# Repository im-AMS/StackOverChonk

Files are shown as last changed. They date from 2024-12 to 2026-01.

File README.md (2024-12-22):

# References

- [custom ergogen-footprints](https://github.com/ceoloide/ergogen-footprints)
- [3d models to view in kicad](https://github.com/joe-scotto/scottokeebs/tree/main/Extras/ScottoKicad)
- [josukey](https://github.com/Narkoleptika/josukey)
- [avocado](https://github.com/auryn31/avocado)
- [supermini pinout specs](https://docs.nordicsemi.com/bundle/ps_nrf52840/page/pin.html)
- [Arduino Pro Micro Pinout](https://cdn.sparkfun.com/assets/9/c/3/c/4/523a1765757b7f5c6e8b4567.png)
- [ergogen configs from Corney-island](https://github.com/ceoloide/corney-island/blob/main/ergogen/config.yaml)
- [svg to points](https://shinao.github.io/PathToPoints/)

# Renders
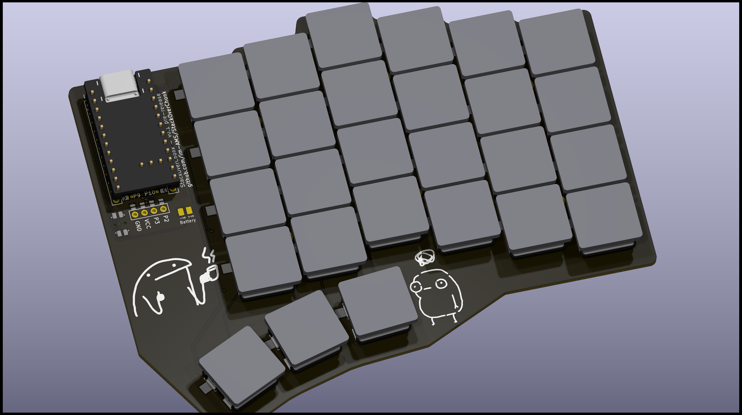
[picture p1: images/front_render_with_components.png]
Front render with components

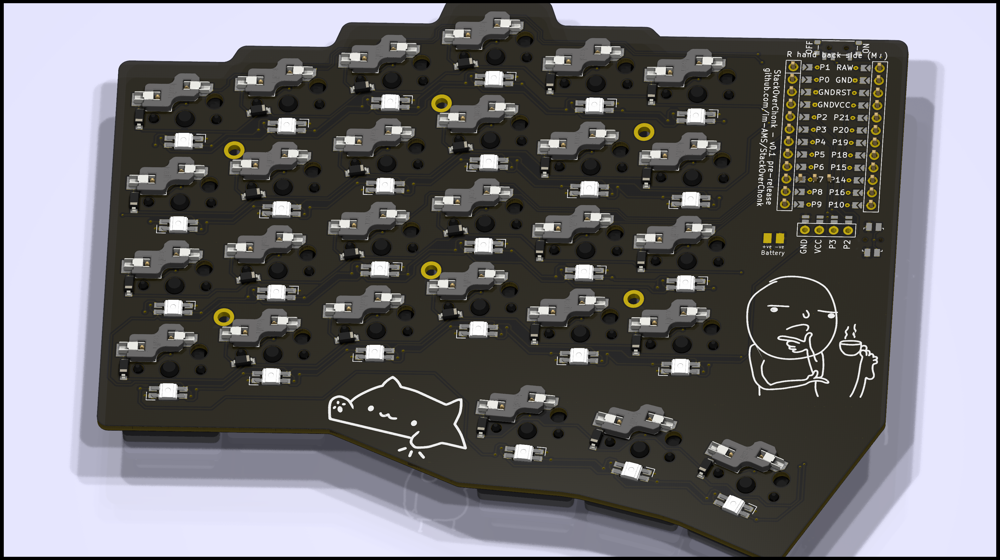
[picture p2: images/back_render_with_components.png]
Back render with components

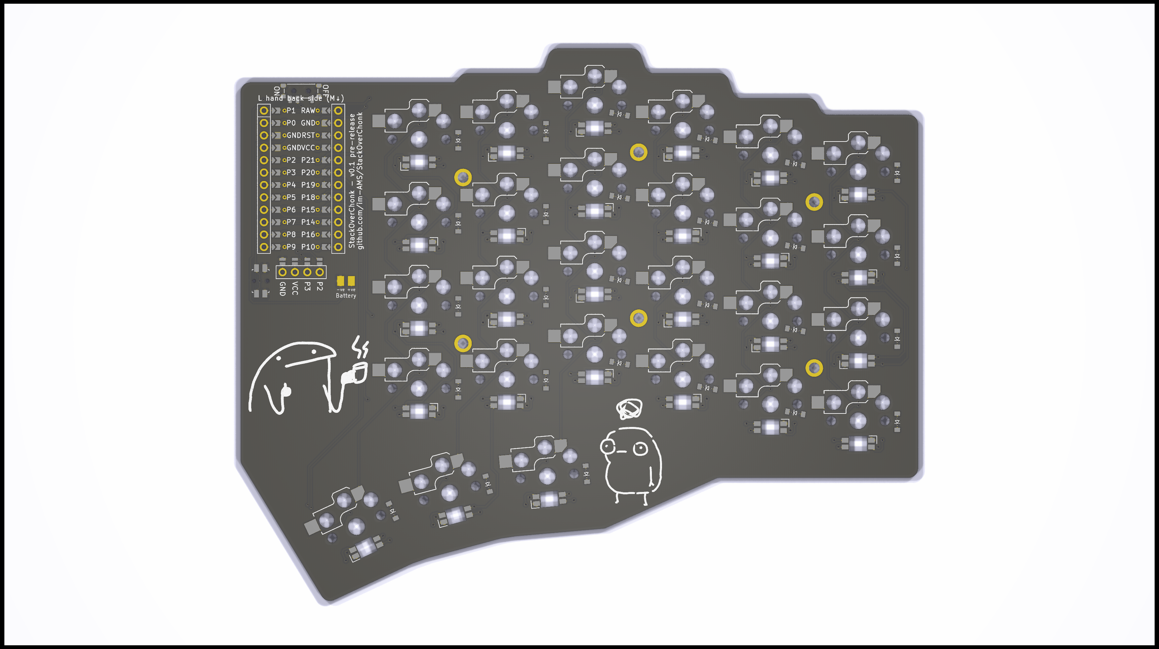
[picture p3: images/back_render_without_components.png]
Front render without components

Back render without components

# Personal Notes and Todos
For RGB Underglow, ZMK docs recomments using high speed gpio pins. refer to the attached pinout specs above.

Try to reserve pins like so (pins in arduino format)
- D2 & D3 for I2C - for Displays
- D6 for high speed comms like RGB underglow, because docs is also using it
- D14, D15, D16 - SPI - idk what i might use this for, just leave em blank

can the battery be connected to RAW for charging or do i have to connect it to top two pins

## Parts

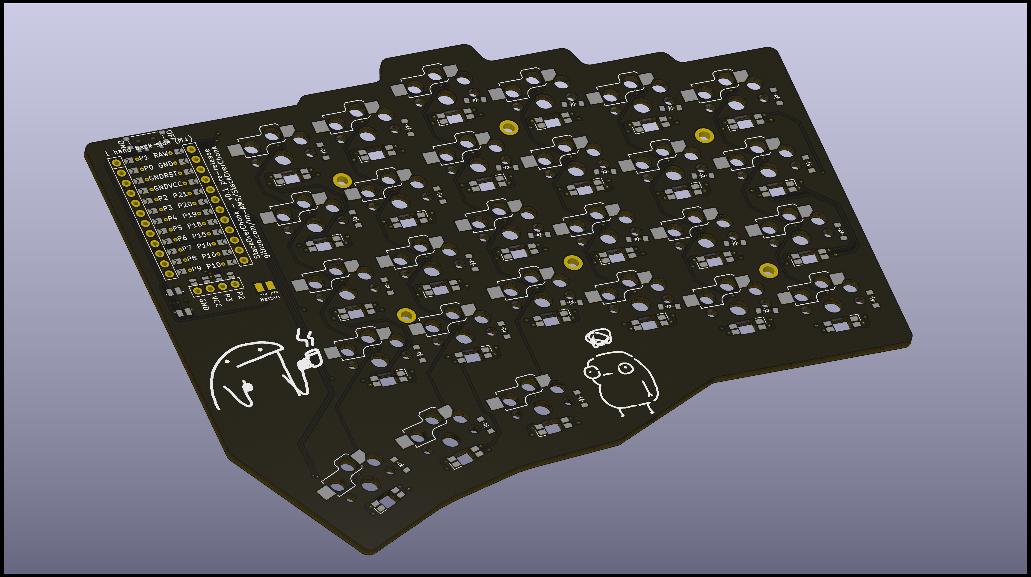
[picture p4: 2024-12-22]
images/front_render_without_components.png

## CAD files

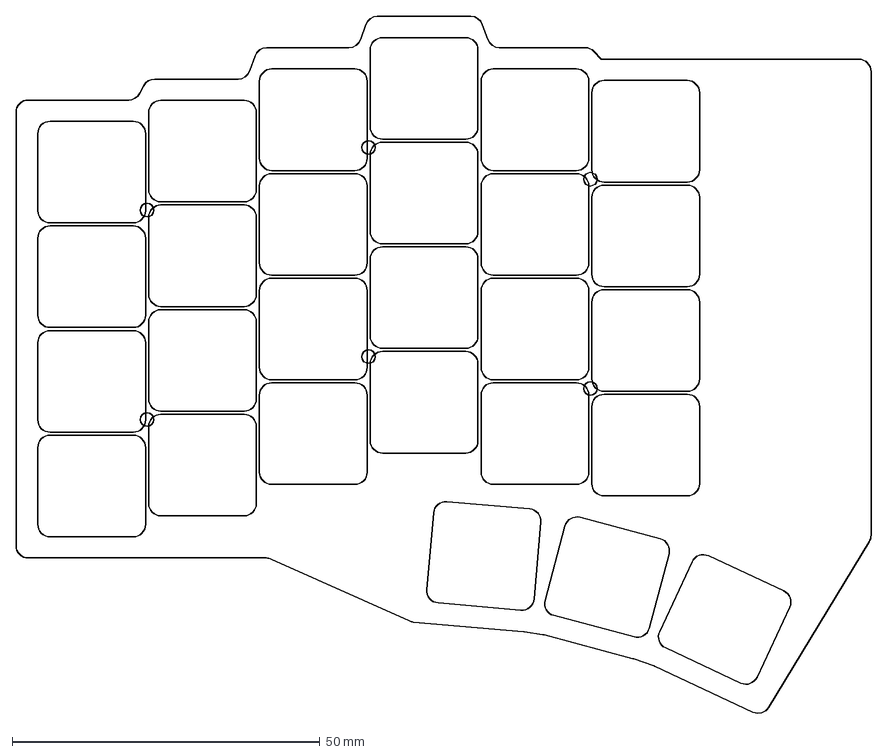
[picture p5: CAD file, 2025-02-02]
ergogen/output/outlines/preview.dxf
138.9 x 113.5 mm

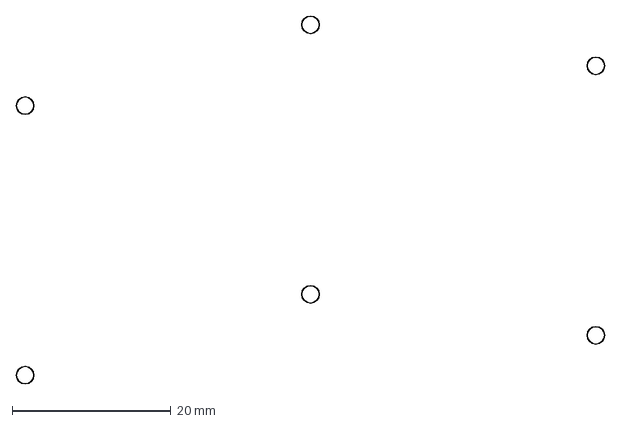
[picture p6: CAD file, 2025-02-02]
ergogen/output/outlines/mounting_holes.dxf
74.2 x 46.4 mm

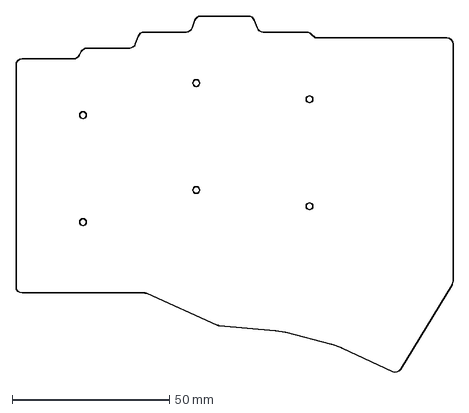
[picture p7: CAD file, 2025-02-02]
ergogen/output/outlines/board_outline.dxf
138.9 x 113.5 mm

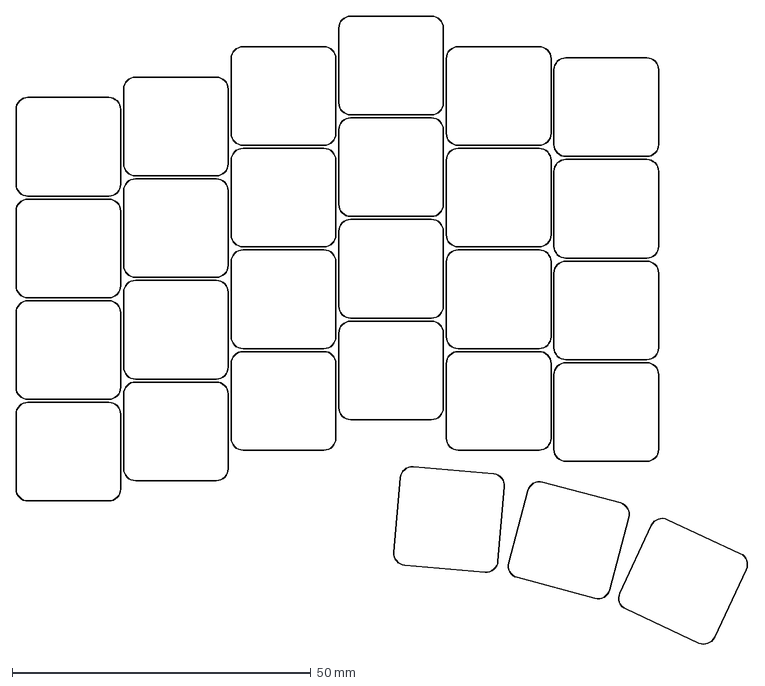
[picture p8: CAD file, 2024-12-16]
ergogen/output/outlines/keycap_outlines.dxf
122.6 x 105.3 mm

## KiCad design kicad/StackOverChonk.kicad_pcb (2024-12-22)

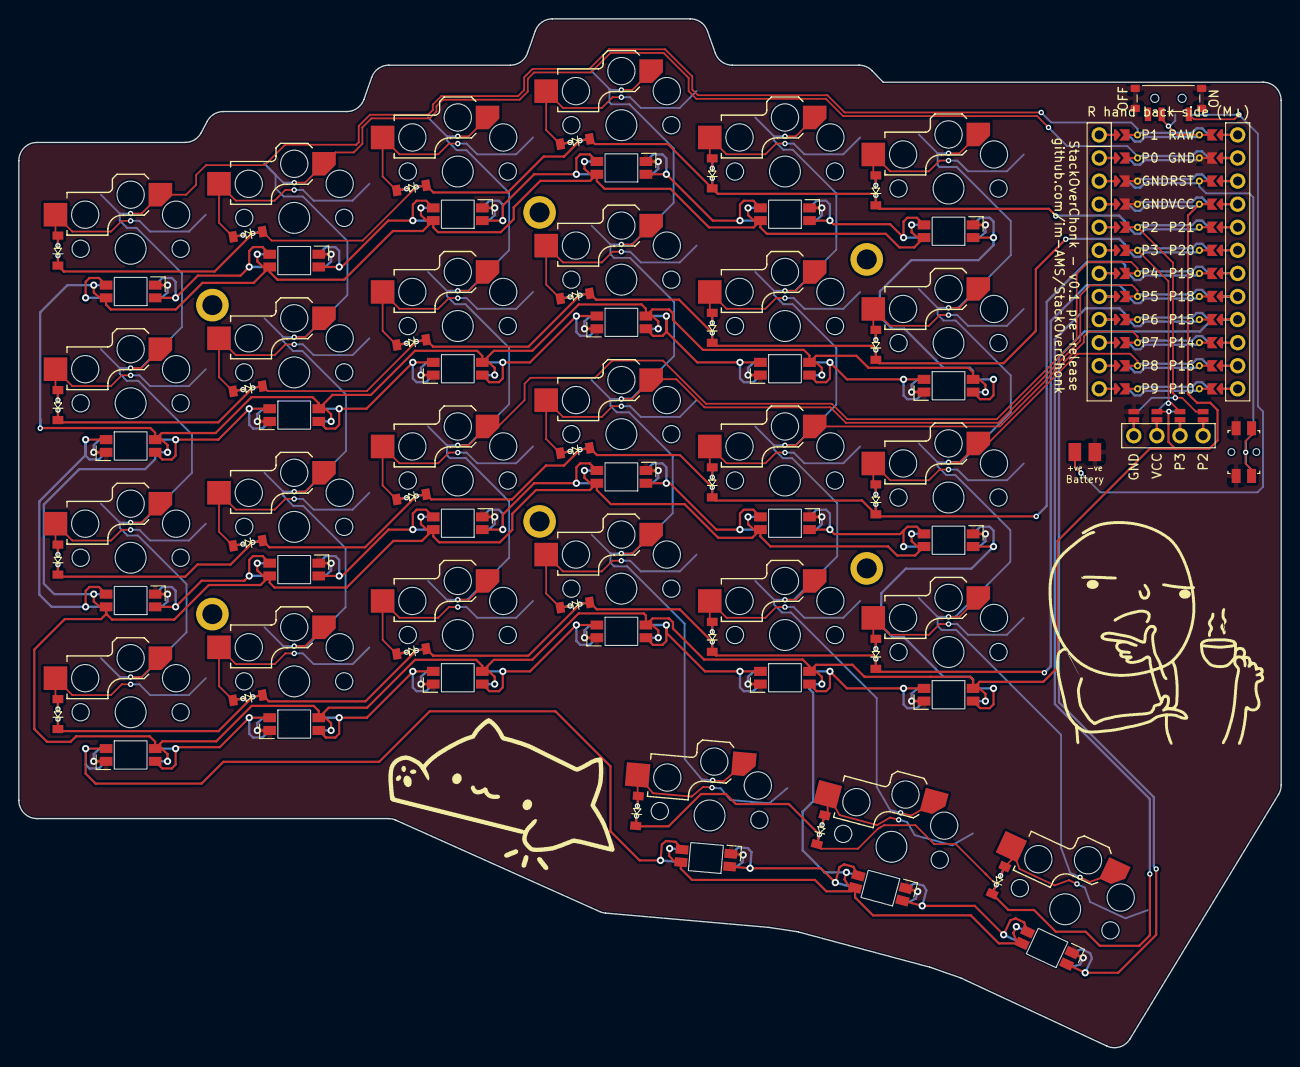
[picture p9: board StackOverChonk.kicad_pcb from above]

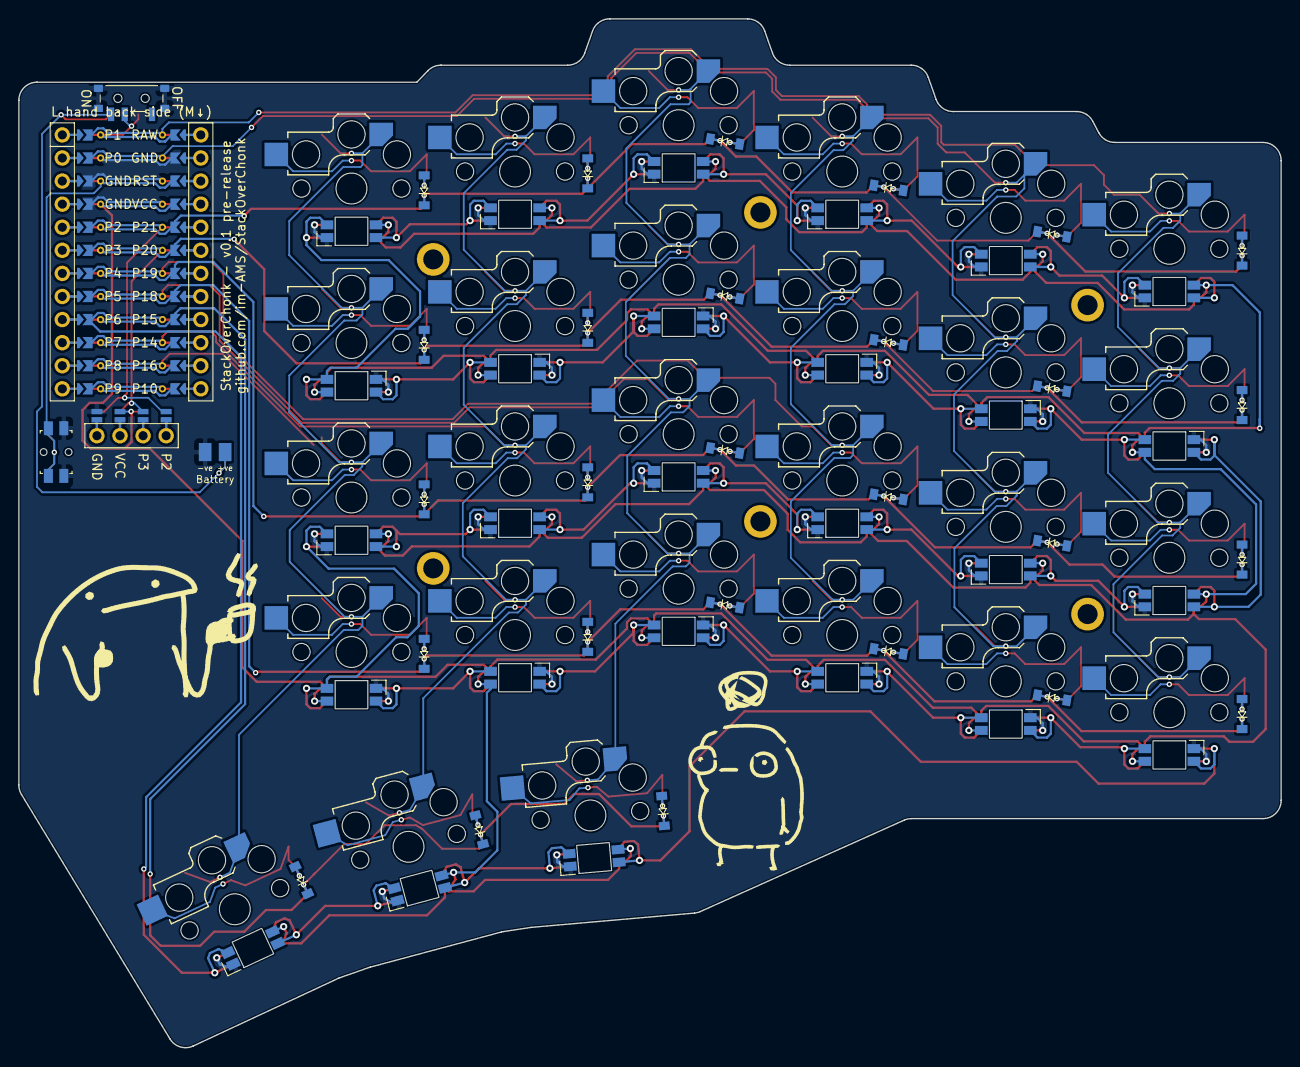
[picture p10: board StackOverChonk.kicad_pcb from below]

Board: 2 copper layers, 138.9 x 113.2 mm, 93 parts (35 on the bottom side), 76 nets.

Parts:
BT1, BT2: Battery_pads
D1, D2, D3, D4, D5, D6, D7, D8, D9, D10, D11, D12, D13, D14, D15, D16, D17, D18, D19, D20, D21, D22, D23, D24, D25, D26, D27: diode_tht_sod123
DISP1: display_ssd1306
H1, H2, H3, H4, H5, H6: mounting_hole_plated
LED1, LED2, LED3, LED4, LED5, LED6, LED7, LED8, LED9, LED10, LED11, LED12, LED13, LED14, LED15, LED16, LED17, LED18, LED19, LED20, LED21, LED22, LED23, LED24, LED25, LED26, LED27: led_SK6812mini-e (per-key, reversible)
MCU1: mcu_supermini_nrf52840
PWR1: power_switch_smd_side
RST1: reset_switch_smd_side
S1, S2, S3, S4, S5, S6, S7, S8, S9, S10, S11, S12, S13, S14, S15, S16, S17, S18, S19, S20, S21, S22, S23, S24, S25, S26, S27: switch_choc_v1_v2

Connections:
DISP1_1: DISP1.1, DISP1.10, DISP1.23
DISP1_2: DISP1.2, DISP1.11, DISP1.22
DISP1_3: DISP1.3, DISP1.12, DISP1.21
DISP1_4: DISP1.4, DISP1.13, DISP1.20
GND: BT1.2, BT2.2, DISP1.14, DISP1.24, LED1.3, LED2.3, LED3.3, LED4.3, LED5.3, LED6.3, LED7.3, LED8.3, LED9.3, LED10.3, LED11.3, LED12.3, LED13.3, LED14.3, LED15.3, LED16.3, LED17.3, LED18.3, LED19.3, LED20.3, LED21.3, LED22.3, LED23.3, LED24.3, LED25.3, LED26.3, LED27.3, MCU1.102, MCU1.121, MCU1.122, PWR1.STAB1, PWR1.STAB2, PWR1.STAB3, PWR1.STAB4, RST1.2, RST1.4
LED_1: LED26.4, LED27.2
LED_2: LED25.4, LED26.2
LED_3: LED1.4, LED25.2
LED_4: LED1.2, LED3.4
LED_5: LED3.2, LED5.4
LED_6: LED5.2, LED7.4
LED_7: LED7.2, LED9.4
LED_8: LED9.2, LED11.4
LED_9: LED11.2, LED23.4
LED_10: LED21.4, LED23.2
LED_11: LED19.4, LED21.2
LED_12: LED17.4, LED19.2
LED_13: LED15.4, LED17.2
LED_14: LED13.4, LED15.2
LED_15: LED2.4, LED13.2
LED_16: LED2.2, LED4.4
LED_17: LED4.2, LED6.4
LED_18: LED6.2, LED8.4
LED_19: LED8.2, LED10.4
LED_20: LED10.2, LED12.4
LED_21: LED12.2, LED24.4
LED_22: LED22.4, LED24.2
LED_23: LED20.4, LED22.2
LED_24: LED18.4, LED20.2
LED_25: LED16.4, LED18.2
LED_26: LED14.4, LED16.2
P0: MCU1.123, S5.1, S6.1, S7.1, S8.1
P1: MCU1.124, S1.1, S2.1, S3.1, S4.1
P2: DISP1.17, DISP1.27, MCU1.120
P3: DISP1.16, DISP1.26, MCU1.119
P4: MCU1.118, S9.1, S10.1, S11.1, S12.1
P5: MCU1.117, S13.1, S14.1, S15.1, S16.1, S25.1
P6: LED27.4, MCU1.116
P7: MCU1.115, S17.1, S18.1, S19.1, S20.1, S26.1
P8: MCU1.114, S21.1, S22.1, S23.1, S24.1, S27.1
P15: D25.1, D26.1, D27.1, MCU1.109
P18: D1.1, D5.1, D9.1, D13.1, D17.1, D21.1, MCU1.108
P19: D2.1, D6.1, D10.1, D14.1, D18.1, D22.1, MCU1.107
P20: D3.1, D7.1, D11.1, D15.1, D19.1, D23.1, MCU1.106
P21: D4.1, D8.1, D12.1, D16.1, D20.1, D24.1, MCU1.105
RAW: MCU1.101, PWR1.2
RST: MCU1.103, RST1.1, RST1.3
VCC: DISP1.15, DISP1.25, LED1.1, LED2.1, LED3.1, LED4.1, LED5.1, LED6.1, LED7.1, LED8.1, LED9.1, LED10.1, LED11.1, LED12.1, LED13.1, LED14.1, LED15.1, LED16.1, LED17.1, LED18.1, LED19.1, LED20.1, LED21.1, LED22.1, LED23.1, LED24.1, LED25.1, LED26.1, LED27.1, MCU1.104
matrix_index_down: D17.2, S17.2
matrix_index_home: D18.2, S18.2
matrix_index_num: D20.2, S20.2
matrix_index_up: D19.2, S19.2
matrix_inner_down: D21.2, S21.2
matrix_inner_home: D22.2, S22.2
matrix_inner_num: D24.2, S24.2
matrix_inner_up: D23.2, S23.2
matrix_middle_down: D13.2, S13.2
matrix_middle_home: D14.2, S14.2
matrix_middle_num: D16.2, S16.2
matrix_middle_up: D15.2, S15.2
matrix_outer_down: D1.2, S1.2
matrix_outer_home: D2.2, S2.2
matrix_outer_num: D4.2, S4.2
matrix_outer_up: D3.2, S3.2
matrix_pinky_down: D5.2, S5.2
matrix_pinky_home: D6.2, S6.2
matrix_pinky_num: D8.2, S8.2
matrix_pinky_up: D7.2, S7.2
matrix_ring_down: D9.2, S9.2
matrix_ring_home: D10.2, S10.2
matrix_ring_num: D12.2, S12.2
matrix_ring_up: D11.2, S11.2
pos: BT1.1, BT2.1, PWR1.1, PWR1.3
thumbs_col1_cluster: D25.2, S25.2
thumbs_col2_cluster: D26.2, S26.2
thumbs_col3_cluster: D27.2, S27.2

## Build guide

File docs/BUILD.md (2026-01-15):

# ZMK Local Build System Documentation

This document explains the local Docker-based build system for the StackOverChonk keyboard firmware.

## Table of Contents

- [Quick Start](#quick-start)
- [Flashing Firmware](#flashing-firmware)
- [Build System Architecture](#build-system-architecture)
- [Deep Dive: How It All Works](#deep-dive-how-it-all-works)

---

## Quick Start

```bash
# Build all firmware (left, right, settings_reset)
make build

# Output files
ls docker/output/
# StackOverChonk_left-nice_nano_v2.uf2
# StackOverChonk_right-nice_nano_v2.uf2
# settings_reset-nice_nano_v2.uf2

# Other commands
make update      # Update ZMK/Zephyr dependencies only
make clean       # Remove build artifacts
make clean-all   # Also clear Docker cached dependencies
```

First build takes ~5-10 minutes (downloads dependencies). Subsequent builds are fast (~1-2 min).

---

## Flashing Firmware

### Method 1: Auto-mount (Easiest)

```bash
# 1. Put keyboard in bootloader mode:
#    - Double-tap the reset button, OR
#    - Hold boot button while plugging in USB

# 2. Wait for it to mount (check dmesg)
dmesg -w
# [xxxxx] usb 1-2: Product: Nice!Nano
# [xxxxx] usb 1-2: Manufacturer: Nice Keyboards
# [xxxxx] usb-storage 1-2:1.0: USB Mass Storage device detected

# 3. Find the mount point
lsblk
# or
findmnt -t vfat

# Usually mounts to /run/media/$USER/NICENANO or /media/$USER/NICENANO

# 4. Copy firmware
cp docker/output/StackOverChonk_left-nice_nano_v2.uf2 /run/media/$USER/NICENANO/

# Keyboard auto-reboots after flashing
```

### Method 2: Manual Mount

```bash
# 1. Put keyboard in bootloader mode (double-tap reset)

# 2. Find the device
lsblk
# Look for something like sda or sdb with ~4MB size

# 3. Mount it
sudo mkdir -p /mnt/keyboard
sudo mount /dev/sda /mnt/keyboard

# 4. Copy and unmount
sudo cp docker/output/StackOverChonk_left-nice_nano_v2.uf2 /mnt/keyboard/
sudo umount /mnt/keyboard

# Keyboard auto-reboots
```

### Method 3: Direct Write (No Mount)

```bash
# 1. Put keyboard in bootloader mode

# 2. Find the device
lsblk
# e.g., /dev/sda

# 3. Write directly using dd (careful with device name!)
sudo dd if=docker/output/StackOverChonk_left-nice_nano_v2.uf2 of=/dev/sda bs=512

# Or use cat
sudo cat docker/output/StackOverChonk_left-nice_nano_v2.uf2 > /dev/sda
```

### Method 4: Using uf2conv (Python)

```bash
# Install uf2conv
pip install uf2conv

# Flash
uf2conv docker/output/StackOverChonk_left-nice_nano_v2.uf2 --deploy
```

### Flashing Script

Create `flash.sh` for convenience:

```bash
#!/bin/bash
set -e

SIDE=${1:-left}
FIRMWARE="docker/output/StackOverChonk_${SIDE}-nice_nano_v2.uf2"

if [ ! -f "$FIRMWARE" ]; then
    echo "Firmware not found: $FIRMWARE"
    echo "Run 'make build' first"
    exit 1
fi

echo "Waiting for keyboard in bootloader mode..."
echo "Double-tap reset button now!"

# Wait for device
while [ ! -d /run/media/$USER/NICENANO ] && [ ! -d /media/$USER/NICENANO ]; do
    sleep 0.5
done

MOUNT=$(find /run/media/$USER /media/$USER -maxdepth 1 -name "NICENANO" 2>/dev/null | head -1)

echo "Found: $MOUNT"
echo "Flashing $SIDE half..."

cp "$FIRMWARE" "$MOUNT/"

echo "Done! Keyboard will reboot."
```

Usage:
```bash
chmod +x flash.sh
./flash.sh left   # Flash left half
./flash.sh right  # Flash right half
```

### Settings Reset

If your keyboard is acting weird (pairing issues, stuck keys, etc.):

```bash
# Flash the settings_reset firmware to clear stored settings
cp docker/output/settings_reset-nice_nano_v2.uf2 /run/media/$USER/NICENANO/

# Then flash the normal firmware again
# (put in bootloader mode again)
cp docker/output/StackOverChonk_left-nice_nano_v2.uf2 /run/media/$USER/NICENANO/
```

---

## Build System Architecture

### Overview

```
Your Config Repo          ZMK Firmware           Zephyr RTOS
     │                        │                      │
     │   ┌────────────────────┴──────────────────────┘
     │   │
     ▼   ▼
   Docker Container (zmkfirmware/zmk-build-arm)
         │
         ▼
   ARM GCC Toolchain compiles → .uf2 firmware
```

### File Structure

```
StackOverChonk/
├── config/
│   ├── west.yml              # West manifest (dependency definitions)
│   ├── StackOverChonk.conf   # Kconfig options (features)
│   └── StackOverChonk.json   # Keyboard layout metadata
├── boards/
│   ├── nice_nano_v2.overlay  # Board customization
│   └── shields/
│       └── StackOverChonk/
│           ├── Kconfig.shield           # Shield declaration
│           ├── Kconfig.defconfig        # Default configs
│           ├── StackOverChonk.dtsi      # Hardware definition
│           ├── StackOverChonk.keymap    # Your keymap
│           ├── StackOverChonk_left.overlay
│           └── StackOverChonk_right.overlay
├── docker/
│   ├── docker-compose.yml    # Docker configuration
│   ├── build.sh              # Build script
│   ├── update.sh             # Dependency update script
│   └── output/               # Compiled .uf2 files
├── zephyr/
│   └── module.yml            # Declares this as a Zephyr module
└── Makefile                  # Build commands
```

### Docker Configuration

`docker/docker-compose.yml`:
```yaml
version: "3.8"

services:
  firmware:
    image: zmkfirmware/zmk-build-arm:stable
    working_dir: /workspace
    volumes:
      - ..:/workspace                    # Your repo (bind mount)
      - zmk-modules:/workspace/modules   # Cached dependencies
      - zmk-zephyr:/workspace/zephyr
      - zmk-tools:/workspace/tools
      - zmk-zmk:/workspace/zmk
    command: /workspace/docker/build.sh

volumes:
  zmk-modules:
  zmk-zephyr:
  zmk-tools:
  zmk-zmk:
```

Named volumes shadow bind mount paths - dependencies persist between runs while your code changes are reflected immediately.

### Build Script Flow

```
make build
    │
    ▼
docker compose run firmware /workspace/docker/build.sh
    │
    ▼
Container starts with zmkfirmware/zmk-build-arm image
    │
    ▼
build.sh runs inside container:
    ├── west init -l config/ (if needed)
    ├── west config manifest.project-filter (skip unused HALs)
    ├── west update (fetch dependencies)
    ├── west zephyr-export
    ├── west build ... StackOverChonk_left
    ├── west build ... StackOverChonk_right
    ├── west build ... settings_reset
    └── copy .uf2 files to docker/output/
```

---

## Deep Dive: How It All Works

### West - Zephyr's Meta Tool

West manages multiple git repos as one workspace. Your `config/west.yml`:

```yaml
manifest:
  remotes:
    - name: zmkfirmware
      url-base: https://github.com/zmkfirmware
  projects:
    - name: zmk
      remote: zmkfirmware
      revision: v0.3.0
      import: true   # ← Key: imports ZMK's dependencies
```

The `import: true` triggers a chain:
```
Your west.yml
    └── imports ZMK's west.yml
            └── imports Zephyr's west.yml
                    └── imports ALL HALs (hal_stm32, hal_nordic, etc.)
```

The project filter skips HALs we don't need:
```bash
west config manifest.project-filter -- "-hal_stm32 -hal_espressif ..."
```

### Zephyr's Build System - The Unholy Trinity

Three configuration systems merge at build time:

```
┌─────────────┐    ┌─────────────┐    ┌─────────────┐
│   Kconfig   │    │ Devicetree  │    │   CMake     │
│  (features) │    │ (hardware)  │    │  (build)    │
└──────┬──────┘    └──────┬──────┘    └──────┬──────┘
       │                  │                  │
       └────────┬─────────┴─────────┬────────┘
                │                   │
                ▼                   ▼
         autoconf.h            devicetree.h
                │                   │
                └─────────┬─────────┘
                          │
                          ▼
                    C compilation
```

#### Kconfig - Feature Flags

Your `config/StackOverChonk.conf`:
```kconfig
CONFIG_ZMK_RGB_UNDERGLOW=y
CONFIG_WS2812_STRIP=y
CONFIG_BT_CTLR_TX_PWR_PLUS_8=y
```

Becomes `build/zephyr/include/generated/autoconf.h`:
```c
#define CONFIG_ZMK_RGB_UNDERGLOW 1
#define CONFIG_WS2812_STRIP 1
#define CONFIG_BT_CTLR_TX_PWR_PLUS_8 1
```

Kconfig has dependencies:
```kconfig
config ZMK_RGB_UNDERGLOW
    bool "RGB underglow support"
    select LED_STRIP          # Auto-enables LED_STRIP
    select ZMK_LOW_PRIORITY_WORK_QUEUE
```

#### Devicetree - Hardware Abstraction

Your `StackOverChonk.dtsi`:
```dts
/ {
    kscan0: kscan {
        compatible = "zmk,kscan-gpio-matrix";
        diode-direction = "col2row";

        row-gpios
            = <&pro_micro 4 (GPIO_ACTIVE_HIGH | GPIO_PULL_DOWN)>
            // ...
        ;
        col-gpios
            = <&pro_micro 21 GPIO_ACTIVE_HIGH>
            // ...
        ;
    };
};
```

The DTS compiler generates `devicetree.h`:
```c
#define DT_N_S_kscan_P_row_gpios_IDX_0_VAL_pin 4
#define DT_N_S_kscan_P_diode_direction "col2row"
```

#### The Overlay System

Shield overlays **merge** on top of board definitions:

```dts
// StackOverChonk_left.overlay
#include "StackOverChonk.dtsi"

&default_transform {
    col-offset = <6>;  // Left half uses cols 0-5
};
```

The `&kscan0` syntax means "modify the existing node".

### The Build Command Explained

```bash
west build -s zmk/app -d build/left -b nice_nano_v2 -p -- \
    -DZMK_CONFIG="/workspace/config" \
    -DBOARD_ROOT="/workspace" \
    -DSHIELD="StackOverChonk_left"
```

| Flag | Meaning |
|---|---|
| `-s zmk/app` | Source directory (ZMK's CMakeLists.txt) |
| `-d build/left` | Build output directory |
| `-b nice_nano_v2` | Target board (nRF52840) |
| `-p` | Pristine build (clean rebuild) |
| `-DZMK_CONFIG=...` | Where your `.conf` file is |
| `-DBOARD_ROOT=...` | Where to find custom shields |
| `-DSHIELD=...` | Which shield overlay to use |

### Memory Map (nRF52840)

```
0x00000000 ┌─────────────────────┐
           │    MBR (4KB)        │  Master Boot Record
0x00001000 ├─────────────────────┤
           │  SoftDevice (152KB) │  Nordic's BLE stack (closed source)
0x00026000 ├─────────────────────┤
           │                     │
           │  Your App (ZMK)     │  ← zmk.uf2 goes here
           │    (~640KB avail)   │
           │                     │
0x000F4000 ├─────────────────────┤
           │  Settings (16KB)    │  NVS for persistent storage
0x000F8000 ├─────────────────────┤
           │  MBR Params (4KB)   │
0x000FC000 ├─────────────────────┤
           │  Bootloader (24KB)  │  UF2 bootloader
0x00100000 └─────────────────────┘

RAM: 0x20000000 - 0x20040000 (256KB)
     SoftDevice takes ~64KB, you get the rest
```

### ZMK Architecture

```
zmk/app/src/
├── main.c              # Entry point
├── kscan.c             # Keyboard matrix scanning
├── keymap.c            # Layer/keymap handling
├── hid.c               # USB/BLE HID reports
├── split/
│   └── bluetooth/
│       ├── central.c   # Left half (connects to right)
│       └── peripheral.c # Right half (advertises)
├── behaviors/          # What keys do
│   ├── behavior_key_press.c
│   ├── behavior_hold_tap.c
│   └── ...
└── rgb_underglow.c
```

#### Event System

ZMK uses event-driven architecture:

```c
// When a key is pressed, kscan.c raises:
ZMK_EVENT_RAISE(position_state_changed,
    (struct position_state_changed){
        .position = position,
        .state = pressed
    });

// Listeners subscribe:
ZMK_LISTENER(keymap, keymap_listener);
ZMK_SUBSCRIPTION(keymap, position_state_changed);
```

#### Split Communication

```
Left Half (Central)              Right Half (Peripheral)
┌──────────────────┐            ┌──────────────────┐
│ Matrix Scan      │            │ Matrix Scan      │
│      │           │            │      │           │
│      ▼           │            │      ▼           │
│ Local Events     │            │ Position Event   │
│      │           │   BLE      │      │           │
│      ▼           │◄───────────│      ▼           │
│ Merge Events     │  GATT      │ Send to Central  │
│      │           │            │                  │
│      ▼           │            └──────────────────┘
│ Keymap Process   │
│      │           │
│      ▼           │
│ HID Report → USB/BLE to Host
└──────────────────┘
```

Right half scans its matrix, sends position events over BLE to left half. Left half merges them, processes keymap, sends HID reports to computer.

### The UF2 Format

```
┌────────────────────────────────────────┐
│ Block 0                                │
├────────────────────────────────────────┤
│ Magic Start 0: 0x0A324655 ("UF2\n")    │
│ Magic Start 1: 0x9E5D5157              │
│ Flags: 0x00002000 (family ID present)  │
│ Target Addr: 0x00026000                │
│ Payload Size: 256                      │
│ Block Number: 0                        │
│ Total Blocks: N                        │
│ Family ID: 0xADA52840 (nRF52840)       │
│ Data[476]: <256 bytes of firmware>     │
│ Magic End: 0x0AB16F30                  │
├────────────────────────────────────────┤
│ Block 1 ...                            │
└────────────────────────────────────────┘
```

Each 512-byte block contains 256 bytes of firmware. The bootloader reads these from the "fake" USB drive and writes to flash.

### Docker Volume Mounting

```yaml
volumes:
  - ..:/workspace                    # Your repo (bind mount)
  - zmk-modules:/workspace/modules   # Named volume (persistent)
```

Named volumes shadow bind mount paths:

```
Host filesystem          Container filesystem
─────────────────        ─────────────────────
~/StackOverChonk/   ──►  /workspace/
    ├── config/     ──►      ├── config/        (bind mount - your files)
    ├── boards/     ──►      ├── boards/        (bind mount - your files)
    │                        ├── zmk/           (named volume - cached)
    │                        ├── zephyr/        (named volume - cached)
    │                        └── modules/       (named volume - cached)
```

Your code changes reflect immediately. Dependencies persist between runs.

---

## Troubleshooting

### Build fails with "shield not found"
- Check `BOARD_ROOT` is set to `/workspace`
- Verify `boards/shields/StackOverChonk/` exists with `Kconfig.shield`

### Bootloader not appearing
- Try holding reset for 5+ seconds
- Check USB cable (some are charge-only)
- Try different USB port

### Pairing issues after flashing
- Flash `settings_reset` firmware first
- Then flash normal firmware
- Re-pair keyboard

### Build takes forever
- First build downloads ~1GB of dependencies
- Run `make clean-all` and rebuild if volumes are corrupted
- Check internet connection

### Permission denied on flash
- Add yourself to `dialout` group: `sudo usermod -aG dialout $USER`
- Or use `sudo` for mount/copy commands

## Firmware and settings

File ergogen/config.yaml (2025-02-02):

# NOTE: in NRF52840, using P0.13 to low the VCC and 3.3V can be shutoff
# NOTE: D2 / 017 (SDA) and D3 / 020 (SCL) are I2C pins
# refer to the pinout specs from Readme
meta:
  engine: 4.1.0
  author: Aditya

units: 
  kx: cx
  ky: cy
  padd_val: 5
  px: kx + padd_val
  py: ky + padd_val

  outer_boundary: 1.5

  thumb_spread: 1.05kx

  led_pos_x: 0 # Led X position relative to the switch center
  led_pos_y: -4.7 # Led Y position relative to the switch center
  led_rotation: 0 # Led rotation


  # right top edge - its a bit janky
  mcu_pos_x: ( 1.95kx+outer_boundary-8.9 ) + ( -outer_boundary - 2)
  mcu_pos_y: (0.6ky+outer_boundary-14) + ( -outer_boundary - 3)

  oled_pos_x: mcu_pos_x + 0
  oled_pos_y: mcu_pos_y - 3.7

  # relative to matrix_inner_home
  battery_pads_x: 15
  battery_pads_y: 5

  power_switch_x: ( 1.95kx+outer_boundary ) + ( -outer_boundary - 8.9 - 2)
  power_switch_y: (0.6ky+outer_boundary) + ( -outer_boundary - 0.30)

  # relative to matrix_inner_home
  reset_switch_x: 32.5
  reset_switch_y: 22
  reset_switch_rotate: -90

  # relative to matrix_inner_up
  board_info_x: 0.5kx + 4
  board_info_y: 0.5ky
  board_info_rotate: -90




points:
  zones:
    matrix:
      key:
        padding: ky
        spread: kx
      anchor:
        shift: [100, -100] # Fix KiCad placement

      rows:
        down:
          row_net: P18  
        home:
          row_net: P19
        up:
          row_net: P20
        num:
          row_net: P21

      columns:
        outer:
          key:
            col_net: P1
          rows:
            num.key:
              led_prev: LED_26
              led_next: LED_27
            up.key:
              led_prev: LED_15
              led_next: LED_16
            home.key:
              led_prev: LED_14
              led_next: LED_15
            down.key:
              led_prev: LED_3
              led_next: LED_4

        pinky:
          key:
            col_net: P0
            stagger: 0.2 ky
            origin: [0,-ky/2]
          rows:
            num.key:
              led_prev: LED_25
              led_next: LED_26
            up.key:
              led_prev: LED_16
              led_next: LED_17
            home.key:
              led_prev: LED_13
              led_next: LED_14
            down.key:
              led_prev: LED_4
              led_next: LED_5

        ring:
          key:
            col_net: P4
            stagger: 0.3 ky
            origin: [0,-ky/2]
          rows:
            num.key:
              led_prev: LED_24
              led_next: LED_25
            up.key:
              led_prev: LED_17
              led_next: LED_18
            home.key:
              led_prev: LED_12
              led_next: LED_13
            down.key:
              led_prev: LED_5
              led_next: LED_6

        middle:
          key:
            col_net: P5
            stagger: 0.3 ky
            origin: [0,-ky/2]
          rows:
            num.key:
              led_prev: LED_23
              led_next: LED_24
            up.key:
              led_prev: LED_18
              led_next: LED_19
            home.key:
              led_prev: LED_11
              led_next: LED_12
            down.key:
              led_prev: LED_6
              led_next: LED_7

        index:
          key:
            col_net: P7
            stagger: -0.3 ky
            origin: [0,-ky/2]
          rows:
            num.key:
              led_prev: LED_22
              led_next: LED_23
            up.key:
              led_prev: LED_19
              led_next: LED_20
            home.key:
              led_prev: LED_10
              led_next: LED_11
            down.key:
              led_prev: LED_7
              led_next: LED_8

        inner:
          key:
            col_net: P8
            stagger: -0.11 ky
            origin: [0,-ky/2]
          rows:
            num.key:
              led_prev: LED_21
              led_next: LED_22
            up.key:
              led_prev: LED_20
              led_next: LED_21
            home.key:
              led_prev: LED_9
              led_next: LED_10
            down.key:
              led_prev: LED_8
              led_next: LED_9

    thumbs:
      key:
        padding: ky
        spread: thumb_spread
      anchor:
        ref: matrix_inner_down
        shift: [-1.5 kx, -1.01 ky]

      rows:
        cluster:
          row_net: P15
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

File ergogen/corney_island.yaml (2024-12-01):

meta:
  engine: 4.1.0
  name: corney-island
  version: 0.2
  ref: &kb_ref "Corney Island v0.2"
  author: ceoloide
  url: &kb_url https://github.com/ceoloide/corney-island
  # footprint: &switch_footprint "ceoloide/switch_mx"
  footprint: &switch_footprint "ceoloide/switch_choc_v1_v2"
  switch:
    # $extends: presets.mx
    $extends: presets.choc_v1
    # $extends: presets.choc_v2

presets:
  # These presets provide different layout options
  # Select a preset in the `units` section below
  # Note: The appropriate switch footprint will still need to be set in the `pcb` section
  mx:
    # Key and keycap measures
    kx: u # spacing between key centers (X-axis)
    ky: u # spacing between key centers (Y-axis)
    ks: 19 # horizontal space between columns (default: 19)
    kp: 19 # vertical padding between keys (deafult: 19)
    kcow: 14 # key cutout hole width (cherry: 14, choc: 13.8)
    kcoh: 14 # key cutout hole height (cherry: 14, choc: 13.8)
    keycw: 18 # keycap width (cherry: 18, choc: 17.5)
    keych: 18 # keycap height (cherry: 18, choc: 16.5)
    led_pos_x: 0 # Led X position relative to the switch center
    led_pos_y: -4.75 # Led Y position relative to the switch center
    led_rotation: 180 # Led rotation
    vertical_underglow_shift: -0.5 kp # How much to shift underglow leds tied to keys
    vertical_diode_shift: 1.325 # How much to shift to avoid overlap
    horizontal_diode_shift: 7.4
    diode_rotation: 0 # Diode rotation
    switch_rotation: 0 # Hotswap north, led south
  choc_v1:
    # Key and keycap measures
    kx: cx # spacing between key centers (X-axis)
    ky: cy # spacing between key centers (Y-axis)
    ks: 18.5 # horizontal space between columns (default: 19)
    kp: 17.5 # vertical padding between keys (deafult: 19)
    kcow: 13.8 # key cutout hole width (cherry, choc v2: 14, choc v1: 13.8)
    kcoh: 13.8 # key cutout hole height (cherry, choc v2: 14, choc v1: 13.8)
    keycw: 17.5 # keycap width (cherry: 18, choc: 17.5)
    keych: 16.5 # keycap height (cherry: 18, choc: 16.5)
    led_pos_x: 0 # Led X position relative to the switch center
    led_pos_y: 4.7 # Led Y position relative to the switch center
    led_rotation: 0 # Led rotation
    vertical_underglow_shift: -kp + 7.8  # How much to shift underglow leds tied to keys
    vertical_diode_shift: 1.5 # How much to shift to avoid overlap
    horizontal_diode_shift: -0.5 kcow - 0.85
    diode_rotation: -180 # Diode rotation
    switch_rotation: 180 # Hotswap south, led north
  choc_v2:
    # Key and keycap measures
    $extends: presets.choc_v1
    kx: u # spacing between key centers (X-axis)
    ky: u # spacing between key centers (Y-axis)
    ks: 19 # horizontal space between columns (default: 19)
    kp: 19 # vertical padding between keys (deafult: 19)
    keycw: 18 # keycap width (cherry: 18, choc: 17.5)
    keych: 18 # keycap height (cherry: 18, choc: 16.5)

units:
  # The following statements will make the content of the preset
  # available in the units context
  $extends: meta.switch

  hand_rotation: 0

  # Physical measures
  screw_radius: 1.1 # M2 screws
  screw_diameter: screw_radius * 2
  screw_head_radius: 2.05
  screw_head_diameter: screw_head_radius * 2
  spacer_radius: 2.15 # M2 standoffs
  spacer_diameter: spacer_radius * 2
  fillet_radius: 0.5
  pwr_trace_width: 0.25
  gnd_trace_width: 0.25
  signal_trace_width: 0.15
  via_size: 0.56 # JLCPCB min 0.56 | KiCad default 0.8
  via_drill: 0.3 # JLCPCB min 0.3 | KiCad default 0.4

  # Case variables
  case_wall_thickness: 1.2
  pcb_to_case_wall_tolerance: 0.25
  bottom_plate_thickness: 1.0
  top_plate_thickness: 1.6
  internal_distance_between_plates: 4

  # Thumb splay
  splay_thumb_middle: 15
  splay_thumb_far: 15
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

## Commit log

2024-11-30 Initial working commit with Avocado config
    [avocado.kicad_pcb, bottom.kicad_pcb, plate.dxf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]
2024-11-30 I dont wanna loose what i have built so far. so take a commit.
    [aditya.kicad_pcb, avocado.kicad_pcb, board_outline.dxf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]
2024-12-01 added rgb leds!!
    [aditya.kicad_pcb, board_outline.dxf, keycap_outlines.dxf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]
2024-12-16 ft. StackOverChonk
    [aditya.kicad_pcb, board_outline.dxf, keycap_outlines.dxf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]
2024-12-16 fixed cluster pins
    [aditya.kicad_pcb]
2024-12-17 fix diode positoning and multiple others
    [aditya.kicad_pcb]
2024-12-20 some fixes and name pcbname changes
    [StackOverChonk.kicad_pcb]
2024-12-20 hole fixes
    [StackOverChonk.kicad_pcb]
2024-12-22 some changes to diode and hole placement - should fix the unconnected GND plane islanding
    [StackOverChonk.kicad_pcb, StackOverChonk.kicad_sch]
2024-12-22 PCB Routed
    [StackOverChonk.kicad_pcb]
2025-01-18 Changed the case of file names
2025-01-19 Some more changes and trying to check if oled and leds work
2025-01-19 change 4d - pin 0 and 1 are tx and rx, if we disable it it shuuld work no?
2025-01-19 change 4g - changing the i2c pins to the oled connected pins
2025-01-19 change 4i - use the nrf keymapping instead of arduino one
2025-01-19 change 5 - just remove all oled and led and debug only the columns
2025-01-19 change 5a - define pin 0 and 1 as gpio
2025-01-25 change 8: lets try to use different pin for the non working microcontroller
2025-01-25 lets try to enable spi debugging
2025-01-25 lets try to enable only rgb leds now
2025-01-25 damn claude forgot to add brackets
2025-01-28 this should solve connecting via bt when powering through usb power
2025-02-02 added the holes location in dxf file
    [board_outline.dxf, mounting_holes.dxf, preview.dxf]
